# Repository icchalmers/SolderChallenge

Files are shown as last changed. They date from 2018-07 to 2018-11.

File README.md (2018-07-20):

# Solder Challenge

The Solder Challenge is a derivative of the [Solder Challenge by Rick Pennen](https://workspace.circuitmaker.com/Projects/Details/Rick-Pannen/Soldering-Challenge).
It's been updated to favour surface mount components and tweaked to parts I could easily source on RS.

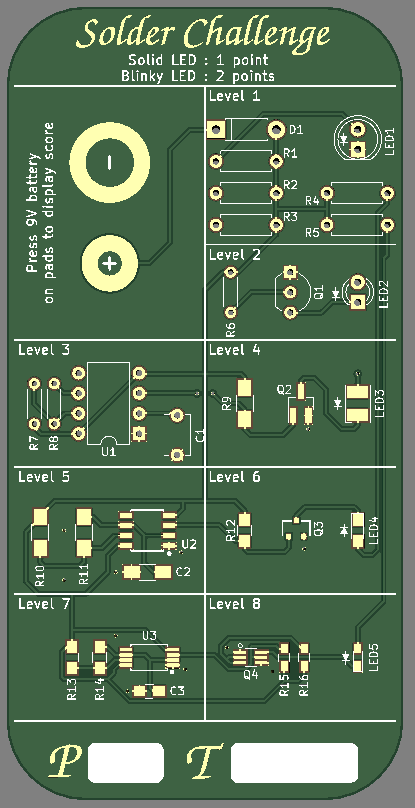
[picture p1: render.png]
3D Render


# Licence

The project is currently licensed under a CC BY-NC-SA licence, as per the original project. Hopefully I'll get permission to remove the NC clause from the original author.

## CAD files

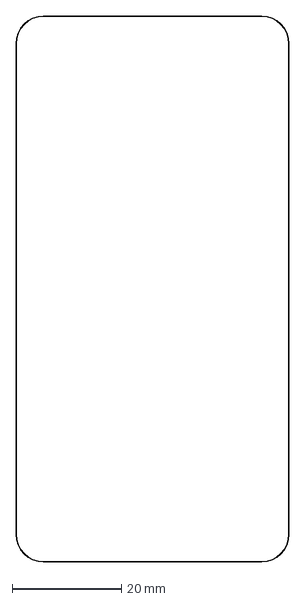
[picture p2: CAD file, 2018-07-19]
board_outline.dxf
50.0 x 100.0 mm

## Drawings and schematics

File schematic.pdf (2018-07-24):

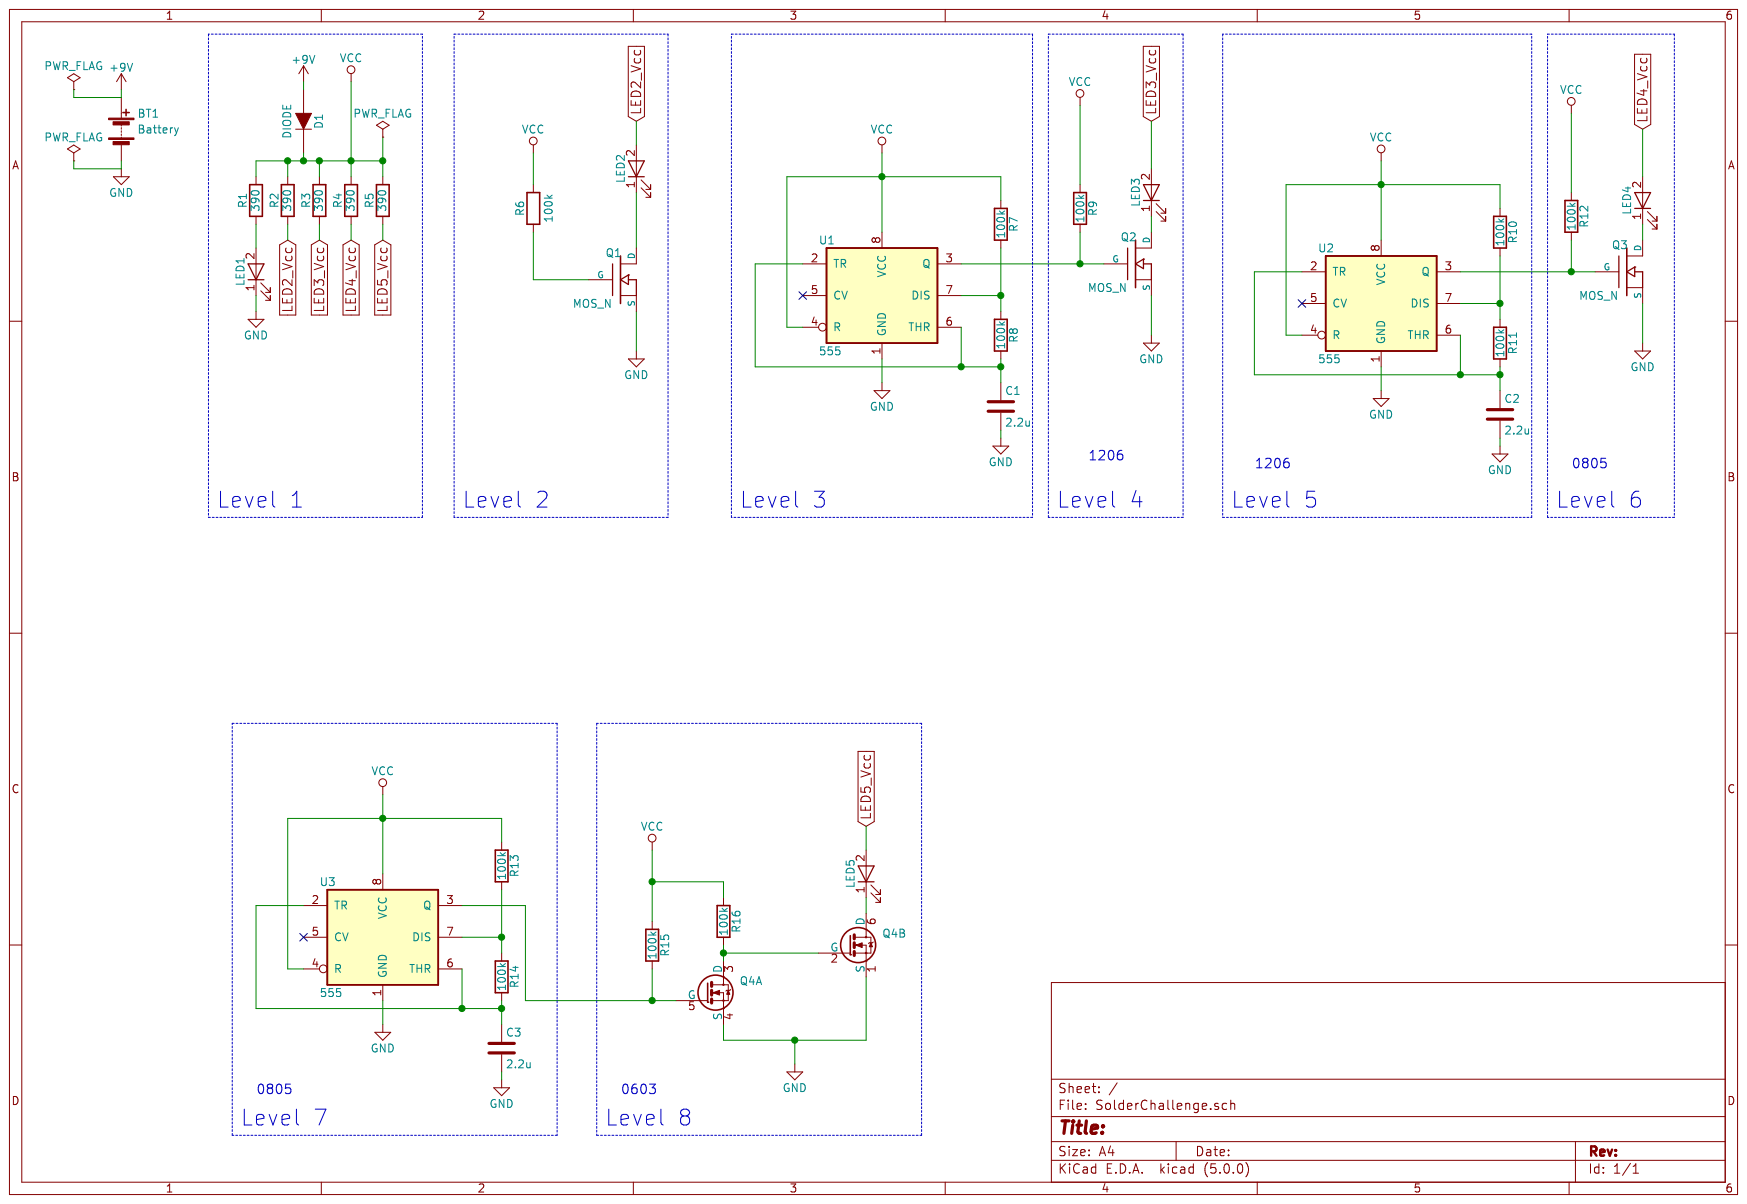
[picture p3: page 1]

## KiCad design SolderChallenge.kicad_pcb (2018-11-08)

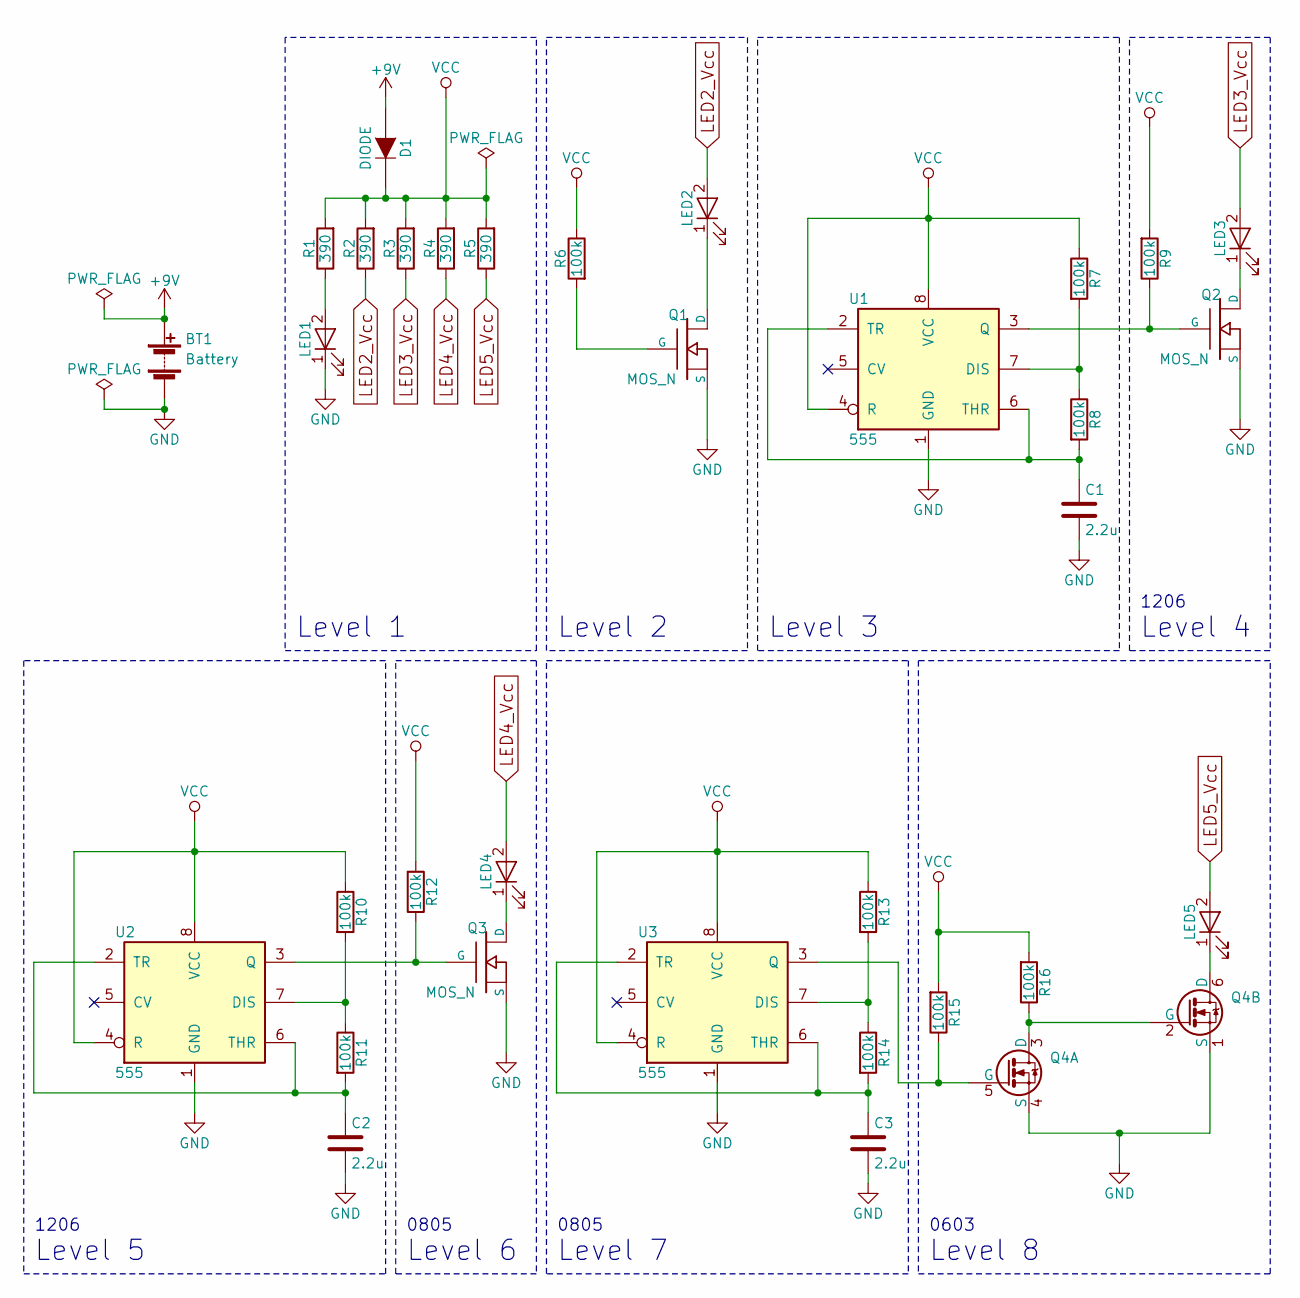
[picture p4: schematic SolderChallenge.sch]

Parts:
BT1: Battery; 9V_bat_press_contact
C1: 2.2u; C_Disc_D5.1mm_W3.2mm_P5.00mm
C2: 2.2u; C_1206_HandSoldering
C3: 2.2u; C_0805_HandSoldering
D1: DIODE; D_DO-41_SOD81_P7.62mm_Horizontal
LED1: LED; LED_D5.0mm
LED2: LED; LED_D3.0mm
LED3: LED; LED_PLCC-2
LED4: LED; LED_0805_HandSoldering
LED5: LED; LED_0603_HandSoldering
Q1: MOS_N; TO-92_Inline_Wide_SGD
Q2: MOS_N; SOT-23_GSD_Handsoldering
Q3: MOS_N; SOT-23_GSD_Nexperia_TO-236AB
Q4: MOS_N_x2; SOT-363_SC-70-6
R1, R2, R3, R4, R5: 390; R_Axial_DIN0207_L6.3mm_D2.5mm_P9.00mm_Horizontal
R6, R7, R8: 100k; R_Axial_DIN0204_L3.6mm_D1.6mm_P5.08mm_Horizontal
R9, R10, R11: 100k; R_1206_HandSoldering
R12, R13, R14: 100k; R_0805_HandSoldering
R15, R16: 100k; R_0603_HandSoldering
U1: 555; DIP-8_W7.62mm
U2: 555; SOIC-8_3.9x4.9mm_Pitch1.27mm
U3: 555; TSSOP-8_4.4x3mm_Pitch0.65mm

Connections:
+9V: BT1.1 (+), D1.A
GND: BT1.2 (-), C1.2, C2.2, C3.2, LED1.1 (K), Q1.S, Q2.S, Q3.S, Q4.1 (S), Q4.4 (S), U1.1 (GND), U2.1 (GND), U3.1 (GND)
LED2_Vcc: LED2.2 (A), R2.1
LED3_Vcc: LED3.2 (A), R3.1
LED4_Vcc: LED4.2 (A), R4.1
LED5_Vcc: LED5.2 (A), R5.1
unnamed: C1.1, R8.2, U1.2 (TR), U1.6 (THR)
unnamed: C2.1, R11.2, U2.2 (TR), U2.6 (THR)
unnamed: C3.1, R14.2, U3.2 (TR), U3.6 (THR)
unnamed: LED1.2 (A), R1.1
unnamed: LED2.1 (K), Q1.D
unnamed: LED3.1 (K), Q2.D
unnamed: LED4.1 (K), Q3.D
unnamed: LED5.1 (K), Q4.6 (D)
unnamed: Q1.G, R6.2
unnamed: Q2.G, R9.1, U1.3 (Q)
unnamed: Q3.G, R12.1, U2.3 (Q)
unnamed: Q4.2 (G), Q4.3 (D), R16.1
unnamed: Q4.5 (G), R15.1, U3.3 (Q)
unnamed: R7.2, R8.1, U1.7 (DIS)
unnamed: R10.2, R11.1, U2.7 (DIS)
unnamed: R13.2, R14.1, U3.7 (DIS)
VCC: D1.C, R1.2, R2.2, R3.2, R4.2, R5.2, R6.1, R7.1, R9.2, R10.1, R12.2, R13.1, R15.2, R16.2, U1.4 (R), U1.8 (VCC), U2.4 (R), U2.8 (VCC), U3.4 (R), U3.8 (VCC)

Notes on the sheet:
Level 1
Level 2
Level 3
Level 4
Level 5
Level 6
Level 7
Level 8
1206
0805
0603

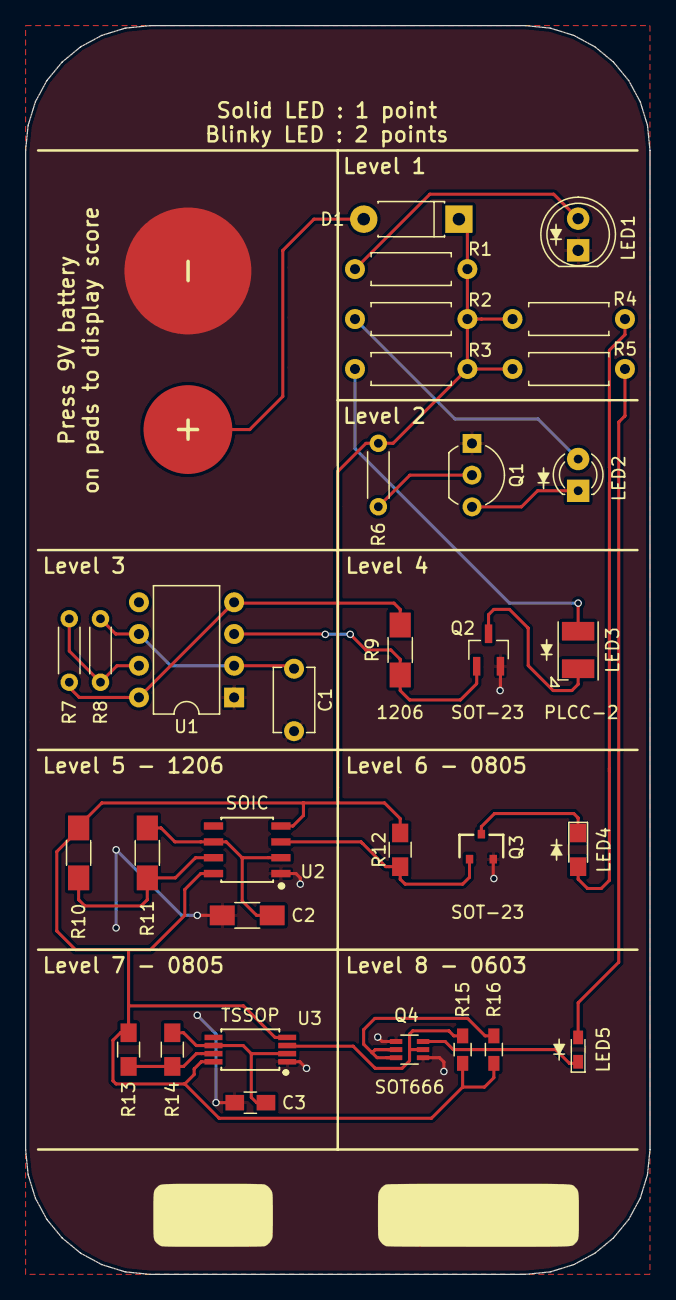
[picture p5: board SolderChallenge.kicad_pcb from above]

Board: 2 copper layers, 50.0 x 100.0 mm, 33 parts (0 on the bottom side), 23 nets.

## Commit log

2018-07-19 Adding CC BY-NC-SA license, as per original Solder Challenge
2018-07-19 Removed battery label to make things look neater
    [SolderChallenge.kicad_pcb]
2018-07-19 Move resistor labels for clarity
    [SolderChallenge.kicad_pcb]
2018-07-19 Switch R4 and R5 for better routing
    [SolderChallenge.kicad_pcb]
2018-07-20 Add PCB render
2018-07-20 Added diode polarity to silkscreen and made all LEDs have cathode at bottom
    [SolderChallenge.kicad_pcb]
2018-07-23 Modified Q1 to use wide variant of package as that's what I ordred. RS had wrong info on site.
    [SolderChallenge.kicad_pcb, SolderChallenge.sch]
2018-07-23 Added gerbers
    [SolderChallenge-B.Cu.gbl, SolderChallenge-B.Mask.gbs, SolderChallenge-B.SilkS.gbo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]
2018-07-24 Update to KiCAD v5.0
    [SolderChallenge.sch]
2018-07-24 Adding pdf of schematic
2018-07-25 Fixed silkscreen markings for pin 1 on U2 and U2. The dot on the silkscreen was implemented as an unnamed pin in the footprint, that only had silkscreen. This displayed fine, but wasn't exported in t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
    [SolderChallenge.kicad_pcb]
2018-07-25 Add name, rev and github URL to back silkscreen
    [SolderChallenge.kicad_pcb]
2018-07-25 Change Q3 to SOT-23 in place of SOT-323. The difference is that the Q3 footprint uses the recommended solder footprint, whereas Q2 uses the KiCAD hand solder footprint. Should be a good example of us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
    [SolderChallenge.kicad_pcb]
2018-07-25 Change C1 to non polarised. Pops would have been fun if people soldered it in round the wrong way, but health and safety prevails over fun :(
    [SolderChallenge.kicad_pcb]
2018-07-25 Switch orientation of one LED to force people to think about orientation. This is to make people more orientation aware without risking an exploding electrolytic in the face
    [SolderChallenge.kicad_pcb]
2018-07-25 Regenerate gerbers for new layout
    [SolderChallenge-B.Cu.gbl, SolderChallenge-B.Mask.gbs, SolderChallenge-B.SilkS.gbo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]
2018-07-25 Disable removal of silkscreen on pads. That's why the pin 1 marker on U2 and U3 footprints wasn't exprting to the gerbers. Using the non-pad based approach is still best option.
    [SolderChallenge.kicad_pcb]
2018-07-25 Forgot to update schematic footprints when I changed them in the layout. I wish KiCAD would automatically back-annotate, or at least let you choose to
    [SolderChallenge.sch]
2018-08-14 Fix diode polarity. The KiCAD library had the silkscreen wrong. I changed pin numbers to letters A and C to avoid confusion
    [SolderChallenge.kicad_pcb]
2018-08-14 Changed holes on LED 2 from 0.9 mm to 0.7 mm. The holes were way too big for the LED I was using. Actually made it hard to solder
    [SolderChallenge.kicad_pcb]
2018-08-14 Reduce hole size from 1.1 mm to 1.0 mm on diode. Excessively large holes made soldering harder
    [SolderChallenge.kicad_pcb]
2018-08-14 Increase pin spacing on R1-5. Originally used 7.68mm. Increase to 9mm to make insertion easier
    [SolderChallenge.kicad_pcb, SolderChallenge.sch]
2018-08-14 Tighten up silkscreen on 1206 resistors. Should make alignment a bit easier
    [SolderChallenge.kicad_pcb]
2018-08-14 Tweak 0603 LED footprint
    [SolderChallenge.kicad_pcb]
2018-08-14 Add a corner mark on silkscreen for LED 3
    [SolderChallenge.kicad_pcb]
2018-08-14 Reduce pad size on Q2 SOT-23 hand solder package. Pads were so long it made alignment harder, and were unnecessarily wide
    [SolderChallenge.kicad_pcb]
2018-08-14 Decrease pad length on Q4, SOT-666. Long pads made it harder to align
    [SolderChallenge.kicad_pcb]
2018-08-14 Added a name box on back silkscreen
    [SolderChallenge.kicad_pcb]
2018-08-14 Add 'JLCJLCJLCJLC' placement to allow JLCPCB to place order number at right place on board
    [SolderChallenge.kicad_pcb]
2018-08-14 Move order number placement label to back silkscreen
    [SolderChallenge.kicad_pcb]
2018-08-14 Update gerbers
    [SolderChallenge-B.Cu.gbl, SolderChallenge-B.Mask.gbs, SolderChallenge-B.SilkS.gbo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]
2018-08-14 Update zip of gerbers
2018-08-27 Update gerbers. Guess who re-sent V1 to the fabhouse a 2nd time...
    [SolderChallenge-B.Cu.gbl, SolderChallenge-B.Mask.gbs, SolderChallenge-B.SilkS.gbo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]
2018-08-27 Moved C1 silk
    [SolderChallenge-B.Cu.gbl, SolderChallenge-B.Mask.gbs, SolderChallenge-B.SilkS.gbo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]
2018-09-14 Add manufacturers part number to schematic symbols
    [SolderChallenge.sch]
2018-09-14 Add interactive BOM generated with InteractiveHtmlBom
2018-11-08 Forgot a few size labels
    [SolderChallenge.kicad_pcb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]
